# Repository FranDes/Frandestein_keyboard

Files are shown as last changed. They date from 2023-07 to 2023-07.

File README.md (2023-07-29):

# Frandestein_keyboard
_Everything about my (first?) handwired custom split keyboard._

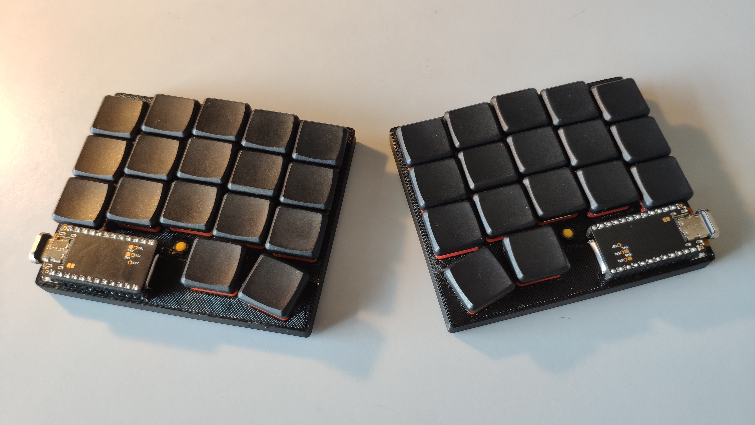
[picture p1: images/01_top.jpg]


## How it started
Before making this, I was using a [Lily58L](https://www.reddit.com/r/MechanicalKeyboards/comments/n2makg/probably_its_not_the_prettiest_but_im_so_proud_of/) (mainly from Keycapsss.com), then a [CRKBD](https://www.reddit.com/r/MechanicalKeyboards/comments/sgetwt/i_see_a_keyboard_and_i_want_it_painted_black/) (again, mainly from Keycapsss.com). After using both of them (especially the Lily), I felt like I needed a more compact and minimalistic keyboard, so I ended up designing one by myself. I called it Frandestein because that's one of my other nicknames, but also because it was created taking inspiration from other keyboards and built with parts taken from other electronic accessories, so it reminded me of Frankenstein.

## Sources of inspire
For the layout, I took inspiration from the [CRKBD](https://github.com/foostan/crkbd) and the [Boardsource's Microdox](https://boardsource.xyz/store/5f2e7e4a2902de7151494f92).

For the designing and building processes, these videos were really helpful:
* [How to Design Mechanical Keyboard Plates and Cases](https://youtu.be/7azQkSu0m_U) by Joe Scotto
* [How to Design a Custom Mechanical Keyboard](https://youtu.be/iv__343ZwE0) by Mad Mod Labs
* [How to Build a Handwired Keyboard](https://youtu.be/hjml-K-pV4E) by Joe Scotto
* [Building Handwired Keyboards with Choc Switches](https://youtu.be/Qkx9M-AzznE) by Joe Scotto

## Designing process
I started with editing a _.json_ file of the CRKBD on [KLE](http://www.keyboard-layout-editor.com/) following the first two videos mentioned above to get the final layout I wanted (sorry, I forgot to save the final _.json_ file...). Then I imported it on kbplate.ai03.com, setting unit width and height to 18 and 17mm. Finally, I downloaded the _.dxf_ file.

Before importing it on Fusion360, I drew a rough sketch of a section view of the keyboard, to understand what would have been the minimum height it could get, considering Choc switch's height and the safest thickness of a 3D printed bottom plate, which I knew is 2mm. Here's the sketch:



As you can see, I also kept note of the nice!nano's dimensions for the final designing process on Fusion, while on the bottom there's what I call [_the tetralobe_](/images/05_bottom_tetralobe.jpg) scheme: it will accommodate one of the four screws (indicated with a _+_ sign) to fix the bottom plate, a magnet (indicated with an _M_), and a little rubber feet (indicated with a _P_), while the fourth hole will accommodate the other half feet. I hope everything will be clearer with this video:

https://github.com/FranDes/Frandestein_keyboard/assets/16577794/49385803-7e35-41c4-909c-84a84e1e15bb

Finally, I modeled the keyboard on Fusion. [Here](/stl) you can find the _.stl_ files.

## Parts
These are the parts I used for this build:

**Original build**
* [3D printed case](/stl)
* [Pro Red Choc switches](https://splitkb.com/collections/switches-and-keycaps/products/kailh-low-profile-choc-switches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)
* [Blank MBK Choc Low Profile Keycaps](https://splitkb.com/collections/switches-and-keycaps/products/blank-mbk-choc-low-profile-keycaps)
* [2x nice!nano's v2](https://splitkb.com/products/nice-nano)
* [MCU sockets](https://www.aliexpress.us/item/32847506950.html)
* [2x MSK-12C02 ON/OFF switches](https://www.aliexpress.us/item/4001202080623.html)
* [2x 401235 Li-ion 3,7V 120mAh batteries](https://www.ebay.it/itm/202170224315)
* 2x reset buttons taken from a dead mouse
* 8x neodymium magnets (for the [carrying solution](https://github.com/FranDes/Frandestein_keyboard/assets/16577794/49385803-7e35-41c4-909c-84a84e1e15bb))
* [THT Diodes](https://splitkb.com/products/tht-diodes)
* Various wires taken from an old SCART cable

**Mods**
* 1mm plexiglass sheet
* [2x normally-closed reed switches](https://www.aliexpress.com/item/1005001688562983.html)

## Building process
Before building the keyboard, I made two little schemes to wire everything correctly. Given that my previous wireless keyboard was a CRKBD, I followed its wiring so that I didn't need to flash a new firmware.

Here are the schemes (_dall'alto_ and _dal basso_ mean _top view_ and _bottom view_):





## Final build



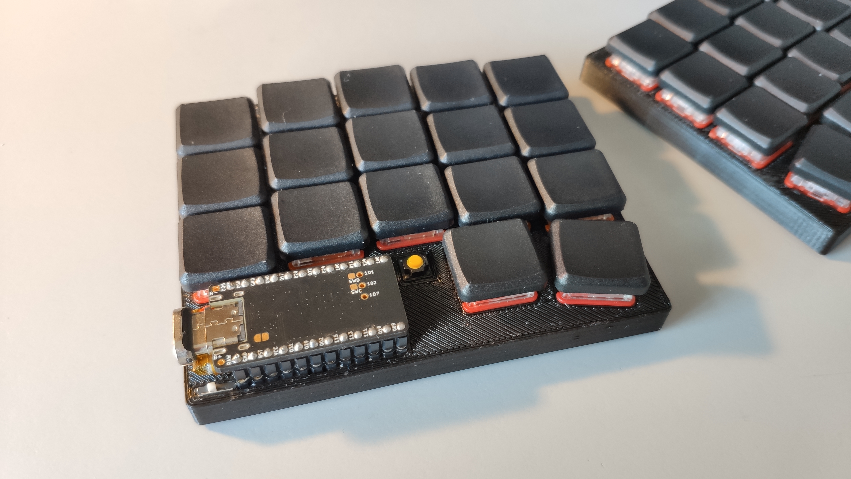
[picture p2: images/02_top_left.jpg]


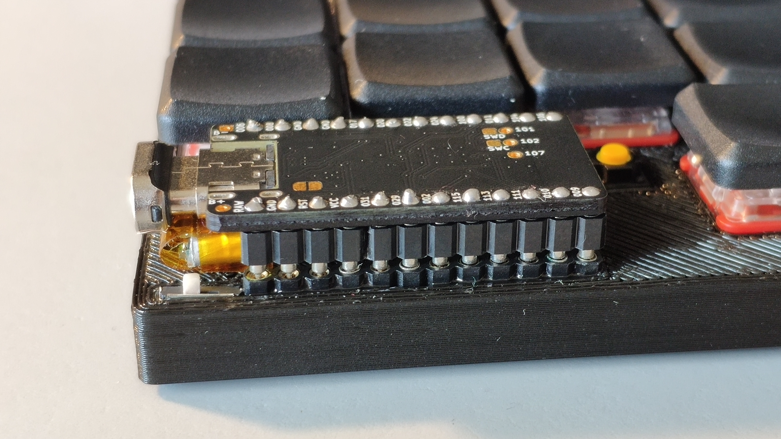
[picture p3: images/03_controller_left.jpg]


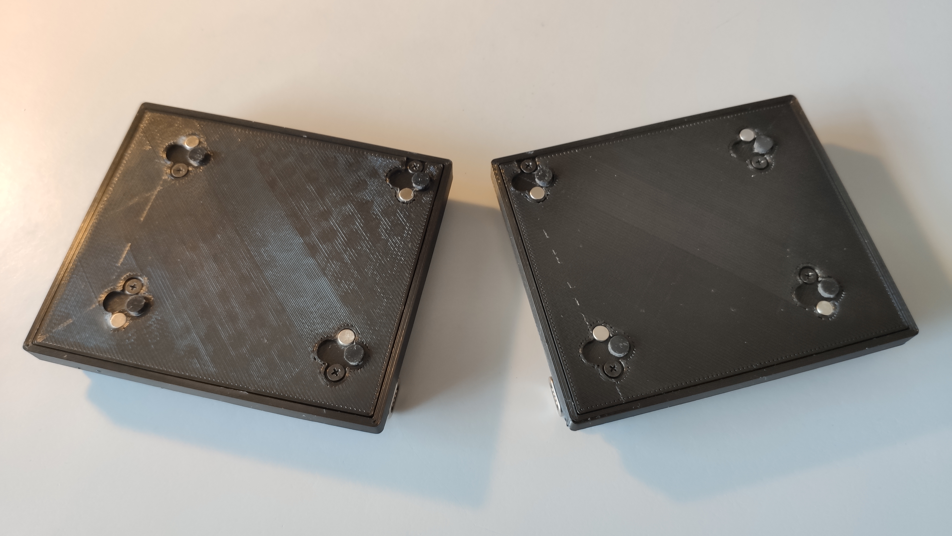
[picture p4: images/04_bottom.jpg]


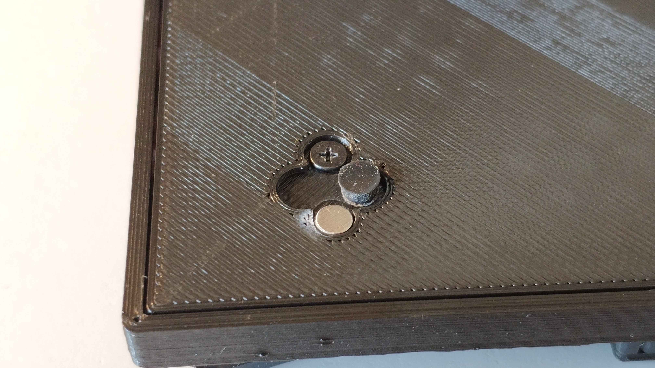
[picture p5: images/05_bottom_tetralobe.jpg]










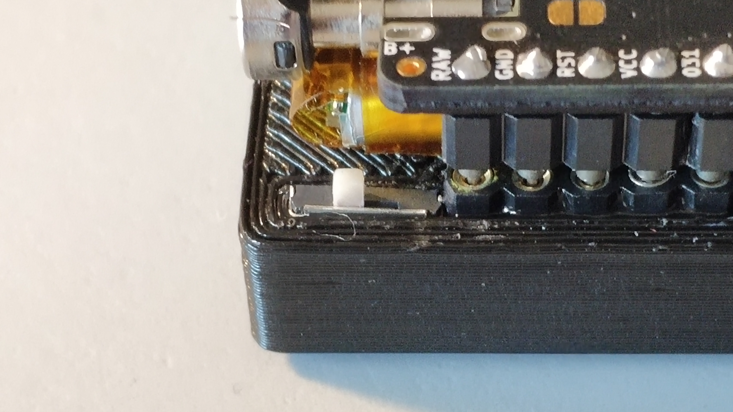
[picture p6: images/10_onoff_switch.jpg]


## Mods

### Mod #1: Transparent bottom
The other day I bought a 1mm sheet of plexiglass to make a transparent bottom. Here's the final result:





### Mod #2: Reed switch for automatic on/off
A couple of weeks ago I learned about reed switches: they close (or open) the circuit when a magnet is near them. Here's how a normally-opened reed switch works:



So I thought it would have been cool to have the keyboard automatically turned off when it's in [carrying mode](https://github.com/FranDes/Frandestein_keyboard/assets/16577794/49385803-7e35-41c4-909c-84a84e1e15bb). I bought [normally-closed reed switches on AliExpress](https://www.aliexpress.com/item/1005001688562983.html) because the circuit should be open only when the keyboard is in carrying mode, while it should be closed the rest of the time. Here's what I received (Choc switch for reference):



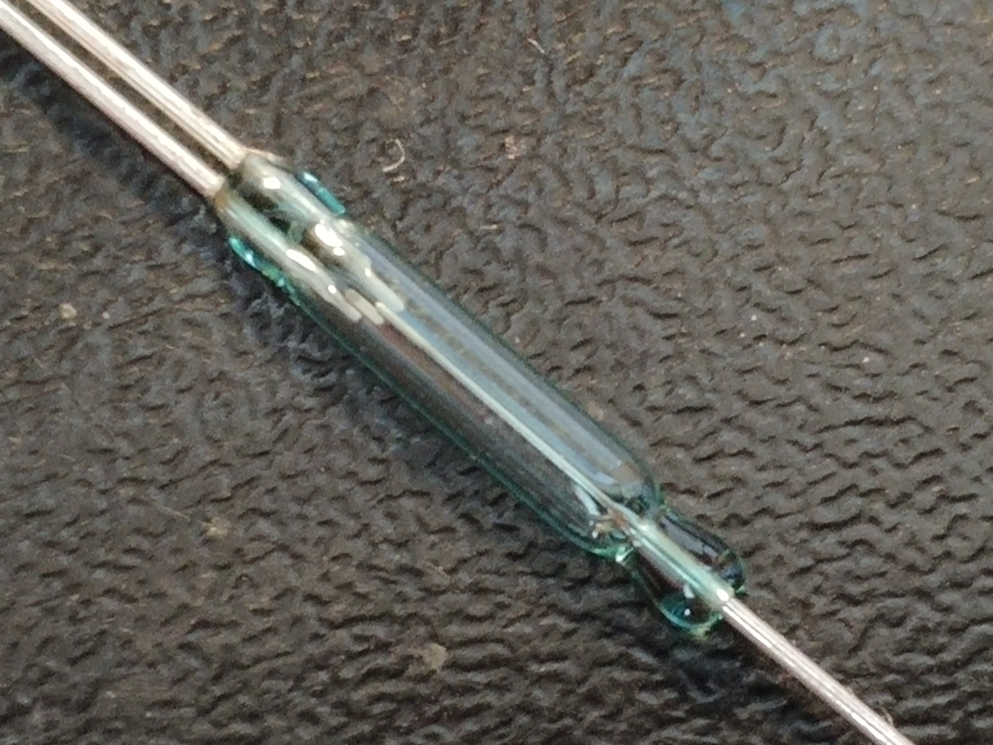
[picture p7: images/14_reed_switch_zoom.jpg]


Instead of removing the two MSK-12C02 on/off switches I already installed, I just added the reed switches in series with them, so that I'm free to choose if I want to turn off the keyboard with the MSK-12C02 switch or by putting it in carrying mode. I hope this scheme (made with Paint :) ) will clarify what I did:

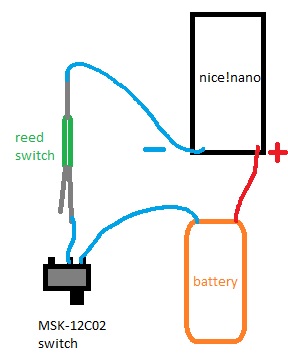
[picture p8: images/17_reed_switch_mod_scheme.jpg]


This is the final result and a [live test](https://imgur.com/a/N7hXu72).





---

I hope you've found all this interesting. I'm here to answer any question.

Have a nice day :)

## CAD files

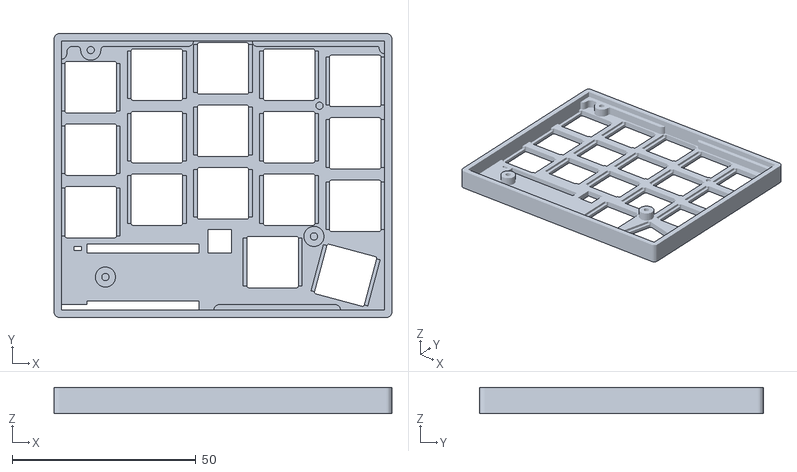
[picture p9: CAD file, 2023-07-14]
stl/Right Switch plate.stl
92.0 x 77.3 x 7.20

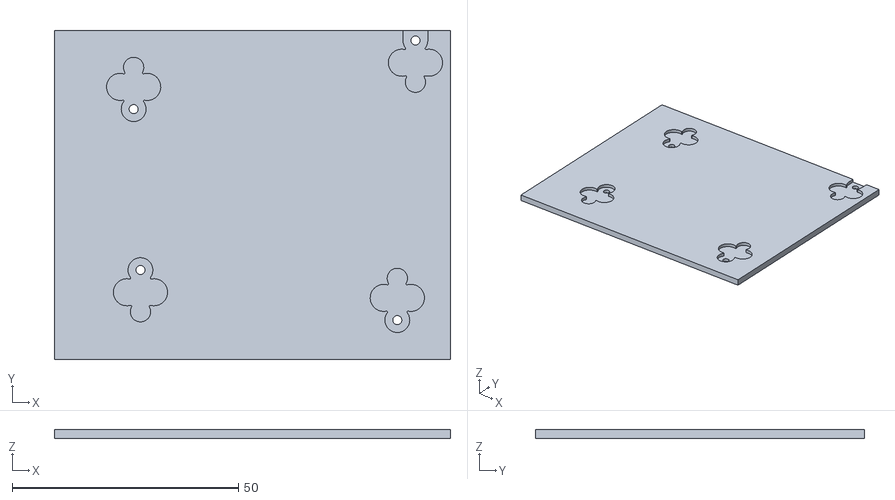
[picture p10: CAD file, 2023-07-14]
stl/Left Bottom plate.stl
87.5 x 72.8 x 2.00

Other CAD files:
stl/Left Switch plate.stl
stl/Right Bottom plate.stl

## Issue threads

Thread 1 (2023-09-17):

About diode

purefall0624, 2023-09-17:
Hello! I must say that what you are dealing with is really attractive! I love it very much. And i have something to say about the pcb. You know that 'crkbd' uses diodes to form the matrix, but 'sweep' from 'davidphilipbarr' uses no diodes. I'm not sure if that would be some help!

FranDes, 2023-09-17:
Hey, thank you so much! I actually considered not using diodes for the handwired build but decided to use them both because I would have to use too many wires, probably taking too much space, and also because I honestly hadn't time to learn how to code ZMK for a custom keyboard, so I decided to follow the CRKBD schematic. I haven't considered using diodes for the PCB version or not; I was thinking of installing them on the upper surface of the PCB, inside the little hole left for the LEDs inside the Choc switches (unfortunately I can't remember a keyboard that is like this, but I'm sure it exists 😅; I'll link it here if I will); I'd like to add a rotary encoder too, so I have to be sure that there are at least two pins for it.

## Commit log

2023-07-14 Create stl
2023-07-14 STL files
    [Left Bottom plate.stl, Left Switch plate.stl, Right Bottom plate.stl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]
2023-07-28 Reed switches mod pictures
2023-07-28 Reed switch scheme
